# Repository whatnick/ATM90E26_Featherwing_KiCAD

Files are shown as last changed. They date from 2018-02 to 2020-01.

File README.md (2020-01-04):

# ATM90E26_Featherwing_KiCAD
ATM90E26 Featherwing with ongoing development in KiCAD
- Previous Eagle version available here: https://github.com/whatnick/ATM90E26_Featherwing
- Arduino Library is available here: https://github.com/whatnick/ATM90E26_Arduino
- Micropython Library is available here: https://github.com/whatnick/ATM90E26_Micropython

# Connection to Host CPU
The boards can be connected in 2 ways with different corresponding jumper settings underneath the board:

- UART mode (default mode)
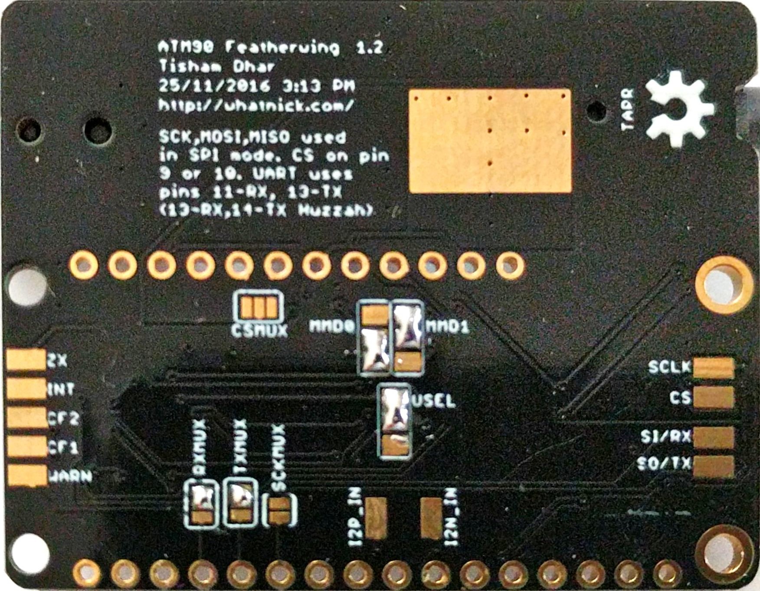
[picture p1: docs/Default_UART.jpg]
UART Mode


- SPI mode (requires resoldering of jumpers)
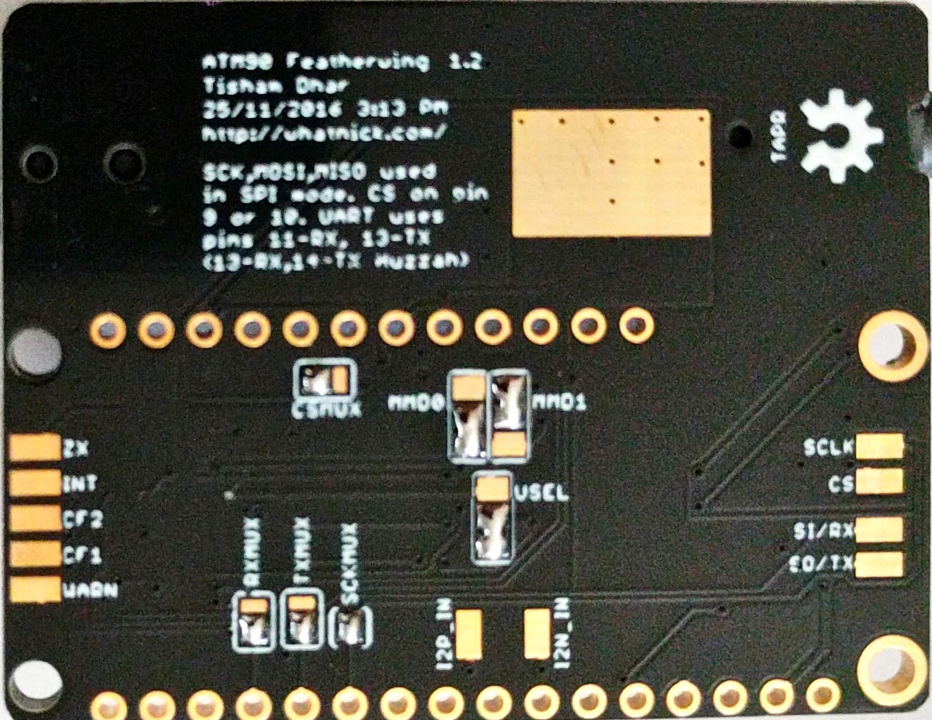
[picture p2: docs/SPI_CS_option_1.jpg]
SPI mode with CS on pin 9
    - With CS on pin 9 
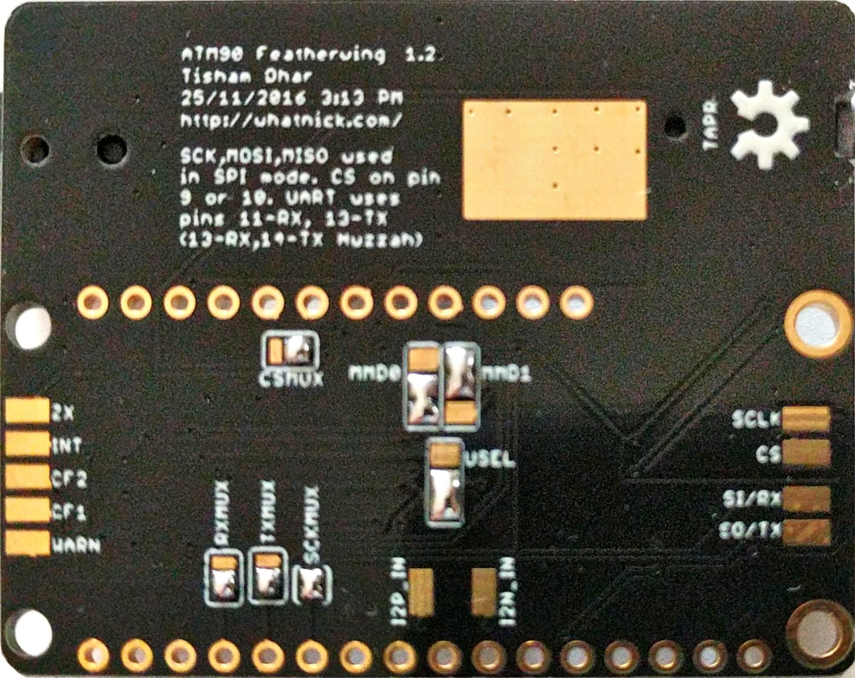
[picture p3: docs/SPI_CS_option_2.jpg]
SPI mode with CS on pin 10
    - With CS on pin 10 

# Metering  modes
Using the MMD jumper various metering modes can be selected as specified by the datasheets.

# Connection to Voltage/Current samplers

The ATM90E26 can acquire 1 voltage and 2 current waveforms to perform energy measurement.
- Voltage sampling using step-down transformer (9V-12V) and voltage divider
- Current sampling using CT with multiplier resistor

# Licence Details
- Hardware License: TAPR 1.0
- Software License: MIT
- Documentation License: CC BY 4.0 International

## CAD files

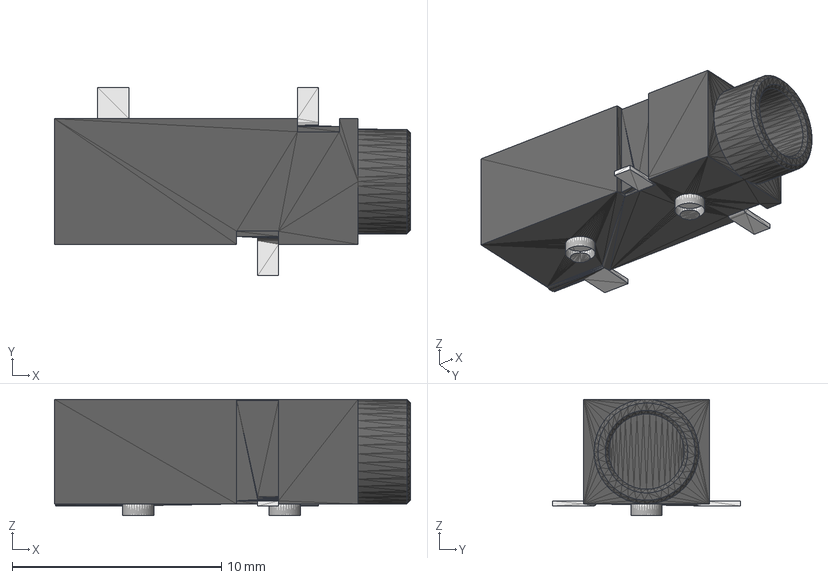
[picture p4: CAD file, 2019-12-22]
3dmodels/CUI_SJ-3523.step
17.0 x 9.00 x 5.80 mm

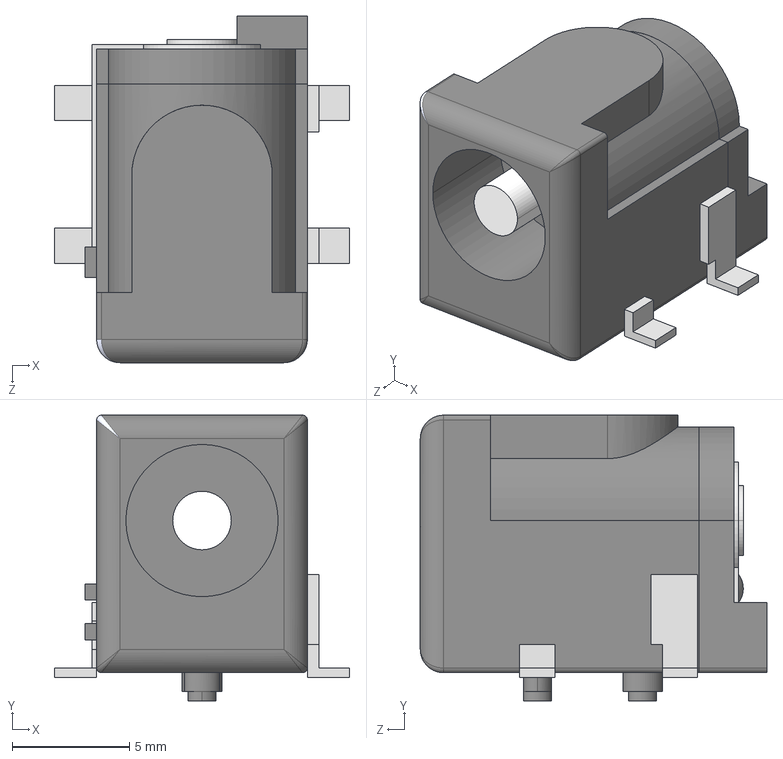
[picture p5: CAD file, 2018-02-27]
3dmodels/CUI_PJ-002BH-SMT-TR.step
12.6 x 12.2 x 14.8 mm

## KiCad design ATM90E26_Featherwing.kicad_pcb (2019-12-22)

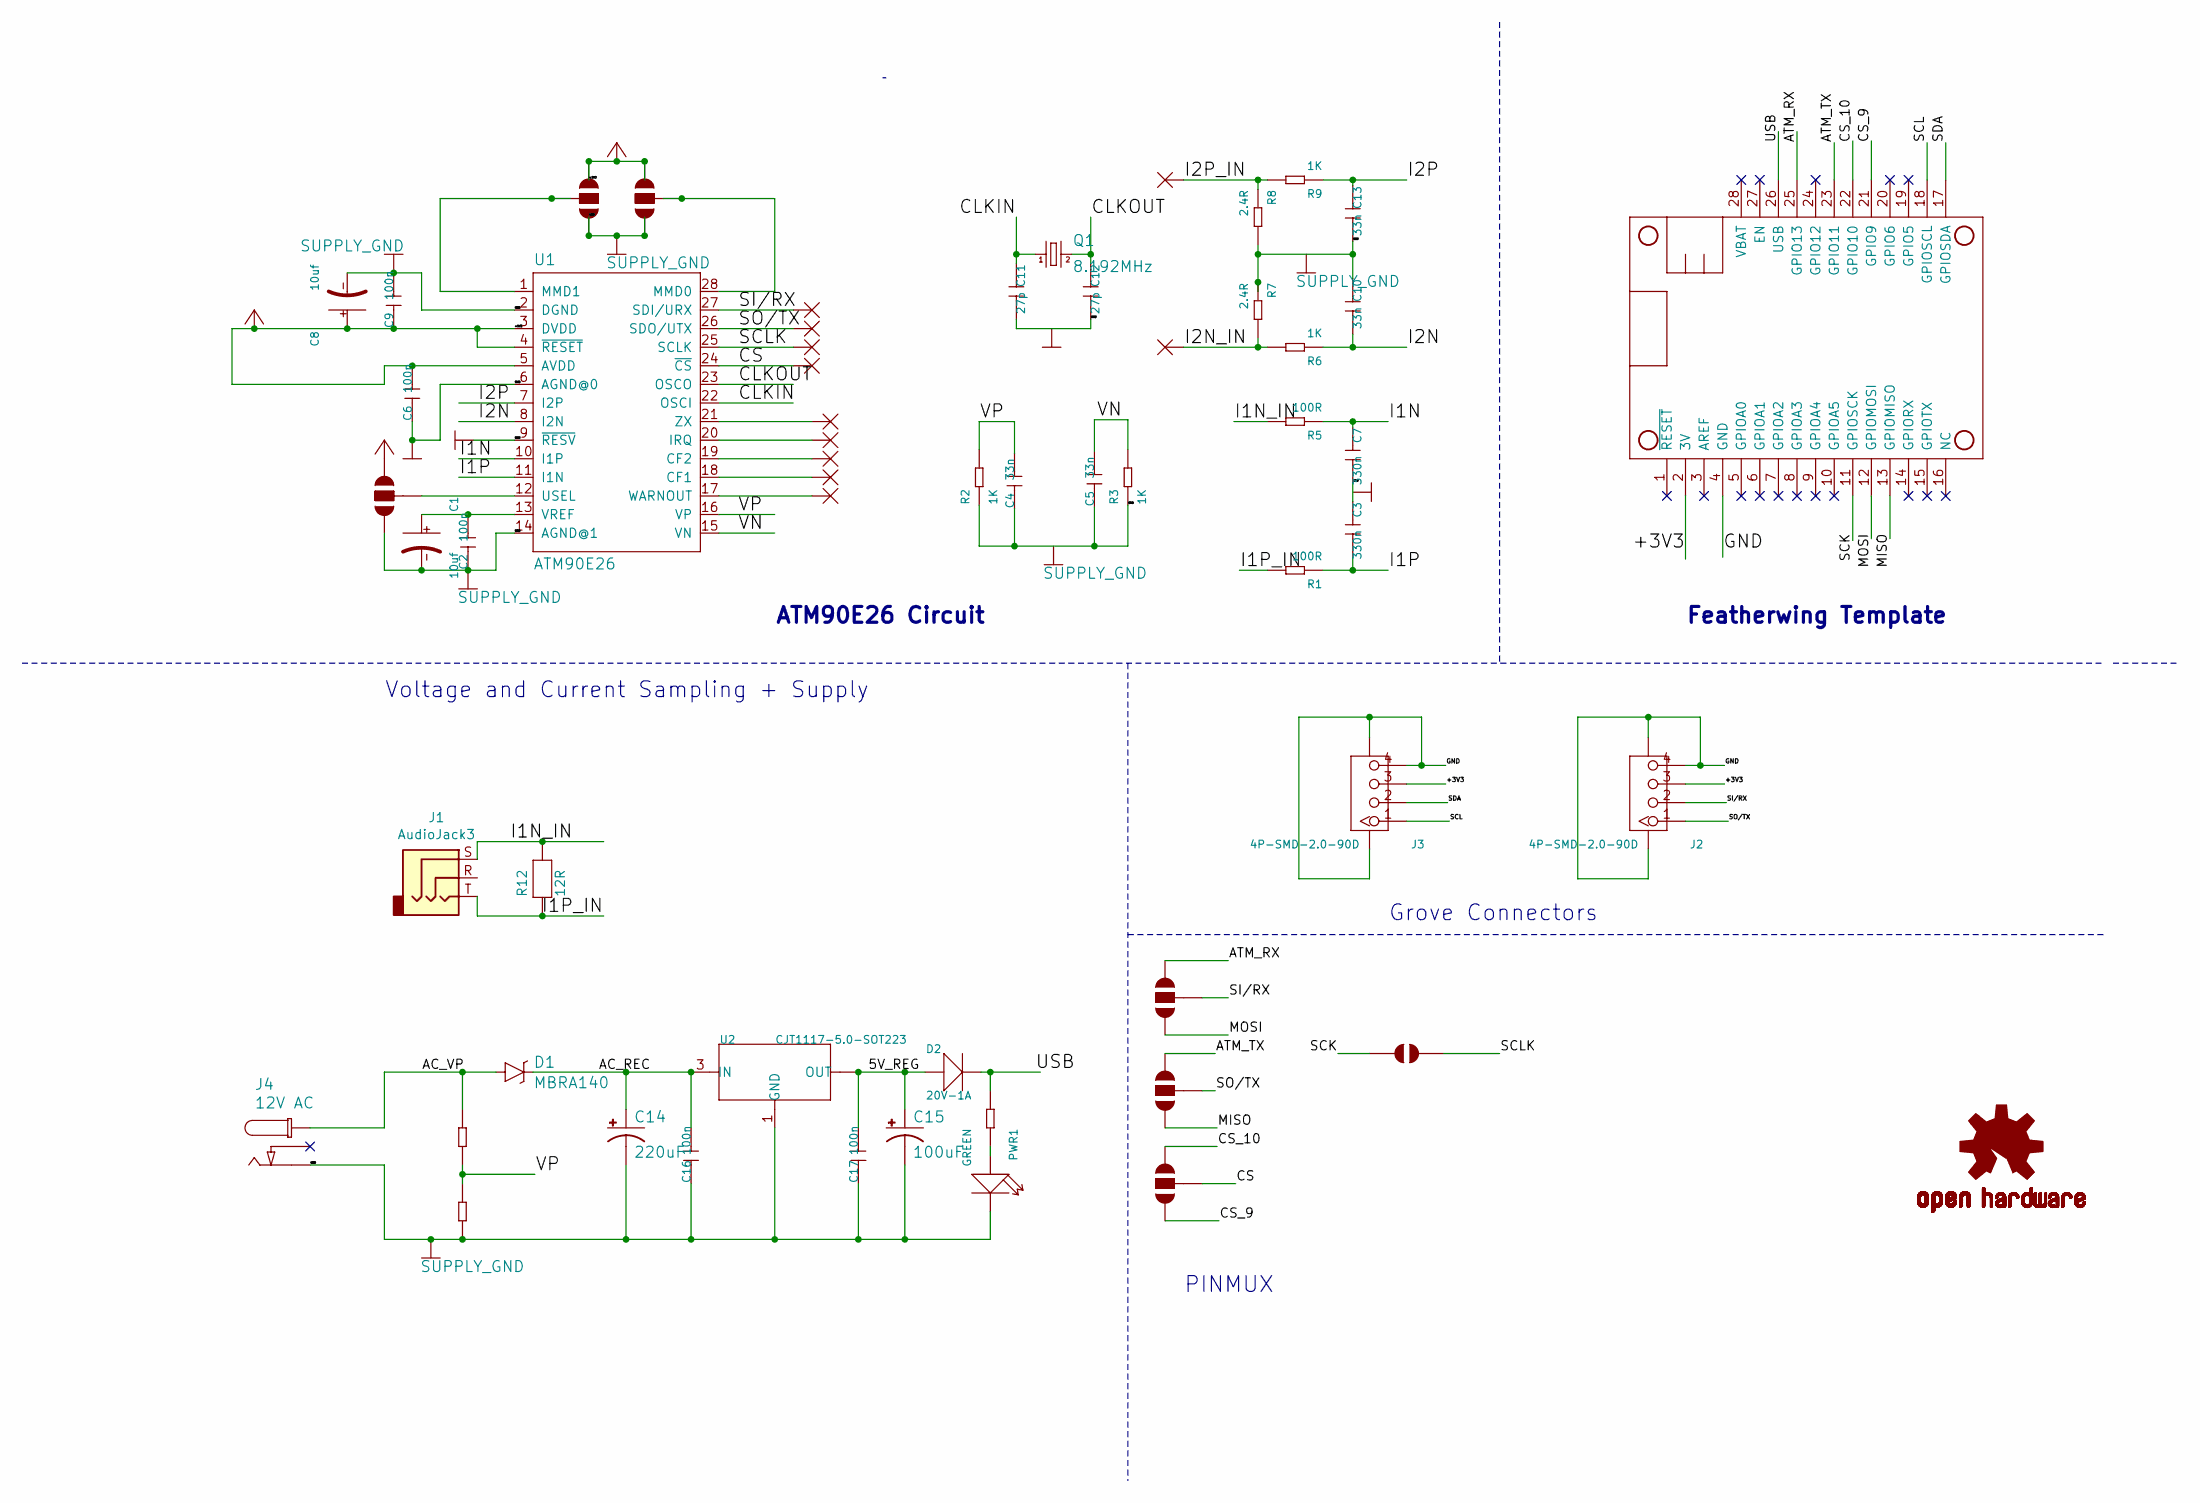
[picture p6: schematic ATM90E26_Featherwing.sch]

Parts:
C1, C8: 10uf; AVX-A
C2, C6, C9, C16, C17: 100n; C0603
C3, C7: 330n; C0603
C4, C5, C10, C13: 33n; C0603
C11, C12: 27p; C0603
C14: 220uF; 140CLH-1010
C15: 100uF; 153CLV-0605
CF1, CF2: WIREPADSMD1,27-254; SMD1,27-2,54
CS1: WIREPADSMD1,27-254; SMD1,27-2,54
CSMUX1: JUMPER-PAD-3-NOYES_SILK; PAD-JUMPER-3-NO_YES_SILK
D1: MBRA140; SMA-DIODE
D2: 20V-1A; SOD-123
I2N_IN1, I2P_IN1: WIREPADSMD1,27-254; SMD1,27-2,54
INT1: WIREPADSMD1,27-254; SMD1,27-2,54
J1: AudioJack3; Jack_3.5mm_CUI_SJ-3523-SMT_Horizontal
J2, J3: 4P-SMD-2.0-90D; HW4-SMD-2.0-90D
J4: 12V AC; DC_BARREL_JACK_SMD_2MM
LOGO1: OSHW-LOGOM; OSHW-Logo2_7.3x6mm_Copper
MMD0, MMD1: JUMPER-PAD-3-NOFULL_BOX_SILK; PAD-JUMPER-3-NO_YES_SILK_FULL_BOX
MS1: FEATHERWING_NODIM; FEATHERWING_DIM
PWR1: GREEN; LED-0603
Q1: 8.192MHz; HC49UP
R1, R5: 100R; R0603
R2, R3, R6, R9, R13: 1K; R0603
R7, R8: 2.4R; R0603
R10: 100K; R0603
R11: INF; R0603
R12: 12R; 0805
RXMUX1: JUMPER-PAD-3-NOYES_SILK; PAD-JUMPER-3-NO_YES_SILK
SCKMUX1: JUMPER-PAD-2-NOYES_SILK; PAD-JUMPER-2-NO_YES_SILK
SCLK1: WIREPADSMD1,27-254; SMD1,27-2,54
SI/RX1: WIREPADSMD1,27-254; SMD1,27-2,54
SO/TX1: WIREPADSMD1,27-254; SMD1,27-2,54
TXMUX1: JUMPER-PAD-3-NOYES_SILK; PAD-JUMPER-3-NO_YES_SILK
U1: ATM90E26; SSOP-28
U2: CJT1117-5.0-SOT223; SOT-223
USEL1: JUMPER-PAD-3-NOFULL_BOX_SILK; PAD-JUMPER-3-NO_YES_SILK_FULL_BOX
WARN1: WIREPADSMD1,27-254; SMD1,27-2,54
ZX1: WIREPADSMD1,27-254; SMD1,27-2,54

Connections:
+3V3: C6.2, C8.+, C9.1, J2.3, J3.3, MMD0.3, MMD1.1, MS1.2 (3V), U1.3 (DVDD), U1.4 (~RESET), U1.5 (AVDD), USEL1.3
/5V_REG: C15.+, C17.2, D2.+, U2.2 (OUT), U2.TER (OUT)
/AC_REC: C14.+, C16.2, D1.C, U2.3 (IN)
/AC_VP: D1.A, J4.P1@2 (P1), R10.1
/ATM_RX: MS1.25 (GPIO13), RXMUX1.3
/ATM_TX: MS1.23 (GPIO11), TXMUX1.3
/CLKIN: C11.1, Q1.1, U1.22 (OSCI)
/CLKOUT: C12.1, Q1.2, U1.23 (OSCO)
/CS: CS1.1, CSMUX1.2, U1.24 (~CS)
/CS_9: CSMUX1.1, MS1.21 (GPIO9)
/CS_10: CSMUX1.3, MS1.22 (GPIO10)
/I1N: C7.1, R5.1, U1.10 (I1P)
/I1N_IN: J1.S, R5.2, R12.2
/I1P: C3.2, R1.1, U1.11 (I1N)
/I1P_IN: J1.T, R1.2, R12.1
/I2N: C10.2, R6.1, U1.8 (I2N)
/I2N_IN: I2N_IN1.1, R6.2, R7.2
/I2P: C13.1, R9.1, U1.7 (I2P)
/I2P_IN: I2P_IN1.1, R8.1, R9.2
/MISO: MS1.13 (GPIOMISO), TXMUX1.1
/MOSI: MS1.12 (GPIOMOSI), RXMUX1.1
/SCK: MS1.11 (GPIOSCK), SCKMUX1.1
/SCL: J3.1, MS1.18 (GPIOSCL)
/SCLK: SCKMUX1.2, SCLK1.1, U1.25 (SCLK)
/SDA: J3.2, MS1.17 (GPIOSDA)
/SI/RX: J2.2, RXMUX1.2, SI/RX1.1, U1.27 (SDI/URX)
/SO/TX: J2.1, SO/TX1.1, TXMUX1.2, U1.26 (SDO/UTX)
/USB: D2.-, MS1.26 (USB), R13.1
/VN: C5.2, R3.2, U1.15 (VN)
/VP: C4.2, R2.2, R10.2, R11.1, U1.16 (VP)
GND: C1.-, C2.1, C3.1, C4.1, C5.1, C6.1, C7.2, C8.-, C9.2, C10.1, C11.2, C12.2, C13.2, C14.-, C15.-, C16.1, C17.1, J2.4, J2.SS1, J2.SS2, J3.4, J3.SS1, J3.SS2, J4.P2, MMD0.1, MMD1.3, MS1.4 (GND), PWR1.-, R2.1, R3.1, R7.1, R8.2, R11.2, U1.2 (DGND), U1.6 (AGND@0), U1.9 (~RESV), U1.14 (AGND@1), U2.1 (GND), USEL1.1
unnamed: C1.+, C2.2, U1.13 (VREF)
unnamed: CF1.1, U1.18 (CF1)
unnamed: CF2.1, U1.19 (CF2)
unnamed: INT1.1, U1.20 (IRQ)
unnamed: MMD0.2, U1.28 (MMD0)
unnamed: MMD1.2, U1.1 (MMD1)
unnamed: PWR1.+, R13.2
unnamed: U1.12 (USEL), USEL1.2
unnamed: U1.17 (WARNOUT), WARN1.1
unnamed: U1.21 (ZX), ZX1.1

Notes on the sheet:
ATM90E26 Circuit
Featherwing Template
Voltage and Current Sampling + Supply
Grove Connectors
PINMUX

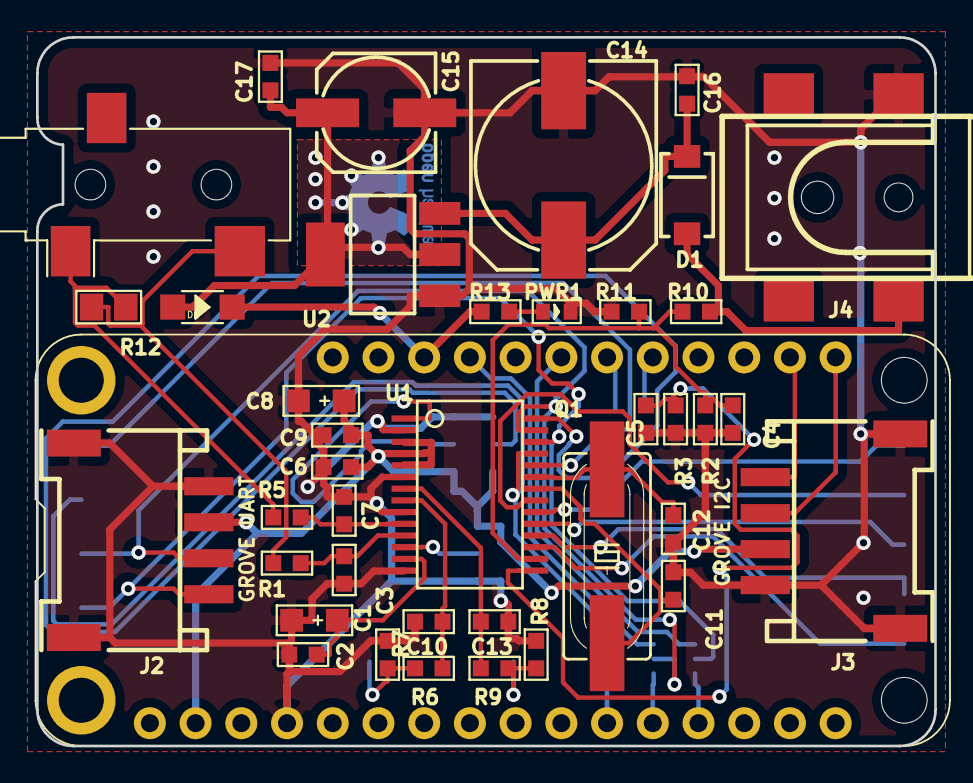
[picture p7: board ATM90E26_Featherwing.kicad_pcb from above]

Board: 2 copper layers, 49.9 x 39.4 mm, 59 parts (0 on the bottom side), 41 nets.

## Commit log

2018-02-26 Initial kicad import
    [ATM90E26_Featherwing.kicad_pcb, ATM90E26_Featherwing.sch]
2018-02-26 Clean out tracks and zones, place parts
    [ATM90E26_Featherwing.dsn, ATM90E26_Featherwing.kicad_pcb, ATM90E26_Featherwing.sch]
2018-02-27 Initial autoroute
    [ATM90E26_Featherwing.dsn, ATM90E26_Featherwing.kicad_pcb, ATM90E26_Featherwing.sch]
2018-02-27 Complete route and clean up silk
    [ATM90E26_Featherwing.kicad_pcb, CUI_PJ-002BH-SMT-TR.step]
2018-02-27 generate gerbers
    [ATM90E26_Featherwing-B.Mask.gbs, ATM90E26_Featherwing-B.Paste.gbp, ATM90E26_Featherwing-B.SilkS.gbo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]
2018-02-28 Adde some more 3d models
    [ATM90E26_Featherwing.kicad_pcb]
2018-11-16 Fixed dangling/disconnected nodes
    [ATM90E26_Featherwing-B.Mask.gbs, ATM90E26_Featherwing-B.Paste.gbp, ATM90E26_Featherwing-B.SilkS.gbo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]
2018-11-20 ERC and connectivity (#1)
    * Add no-connect to unused pins
    * Connect R11 to ground
    * pcb: connect R11 to ground
    [ATM90E26_Featherwing.kicad_pcb, ATM90E26_Featherwing.sch]
2019-12-22 Successfully fabricated and merged with 3-pin stereo (#2)
    * Converted to SJ-3525 for current clamp input
    * Add stitchig vias
    * New gerbers and git ignore of temp files
    [ATM90E26_Featherwing-B.Mask.gbs, ATM90E26_Featherwing-B.Paste.gbp, ATM90E26_Featherwing-B.SilkS.gbo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]
2019-12-22 Upgrade to KiCAD 5 and add iBOM
    [ATM90E26_Featherwing.kicad_pcb, ATM90E26_Featherwing.sch]
2019-12-22 Add full iBOM
    [ATM90E26_Featherwing.sch]
